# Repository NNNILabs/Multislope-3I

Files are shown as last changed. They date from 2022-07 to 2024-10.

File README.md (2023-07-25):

# Multislope 3I 
## Introduction
This repository contains hardware and software files for the third multislope prototype board, designated 3I. This is the most complete and proper version of the PCB so far, including a proper 8-resistor network, an LM399/ADR1399 reference, composite integrator (with two SOIC-8 footprints), shielding on the integrator summing node and test points to easily probe crucial nodes. 
History and operation are documented extensively [here](https://hackaday.io/project/190528-multislope-adc).
## Project Motivation
The second prototype PCB was completed hastily with not much thought put into either layout or choice of parts, so a better-designed (and hopefully better-evaluated) board was in order. 
## Usage
The KiCAD project files can be used to generate gerber files, which can be used to manufacture the PCBs. The code is written in C/C++ in the VScode development environment. Detailed instructions on how to compile the software will be added later. A .uf2 file is present in the project outputs which can be uploaded directly to the Pi Pico. 
## List of Files
- Hardware: KiCAD PCB design files, BOM and schematic. 
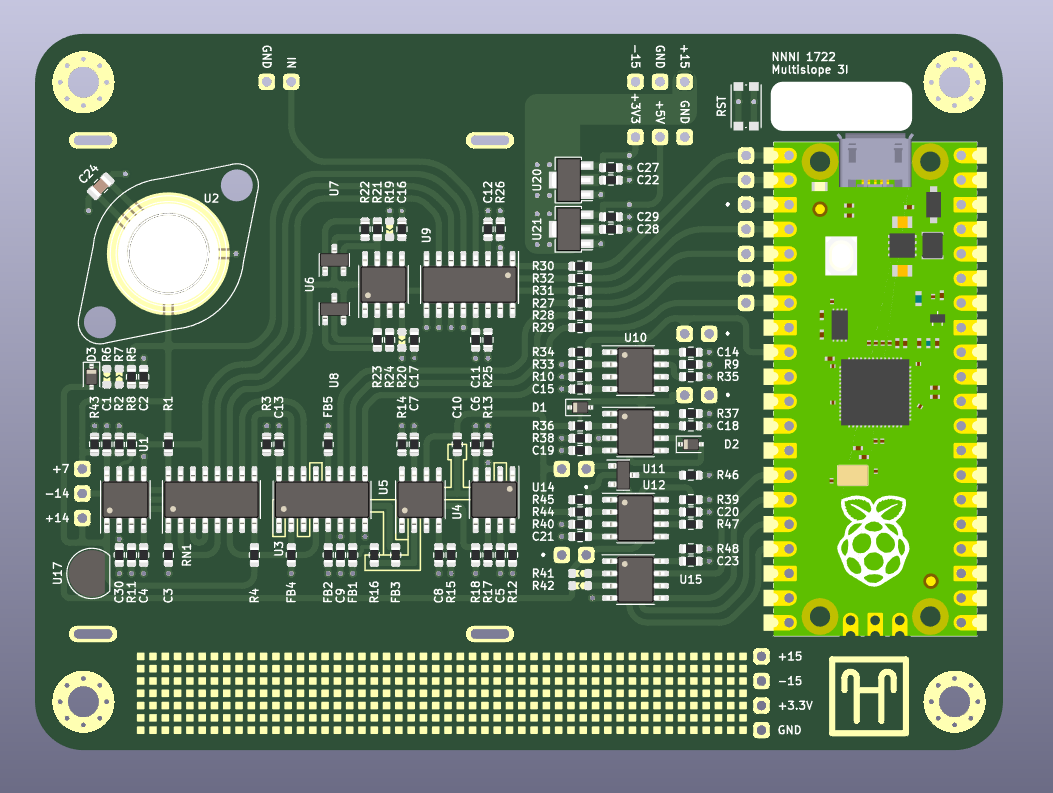
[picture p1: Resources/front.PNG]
Front side of the PCB

- Software: C/C++ code, uf2 file for direct upload. 
- Resources: Infographics
## Application Examples
- The readings from the overall converter (PWM counts and residue) were noisy, and the raw readings from the MCP3202 residue ADC were noisy and contained unexplained banding. Linearity shows a parabolic curve, probably because of wrong constants or small mismatches in switch resistances. 
### Linearity
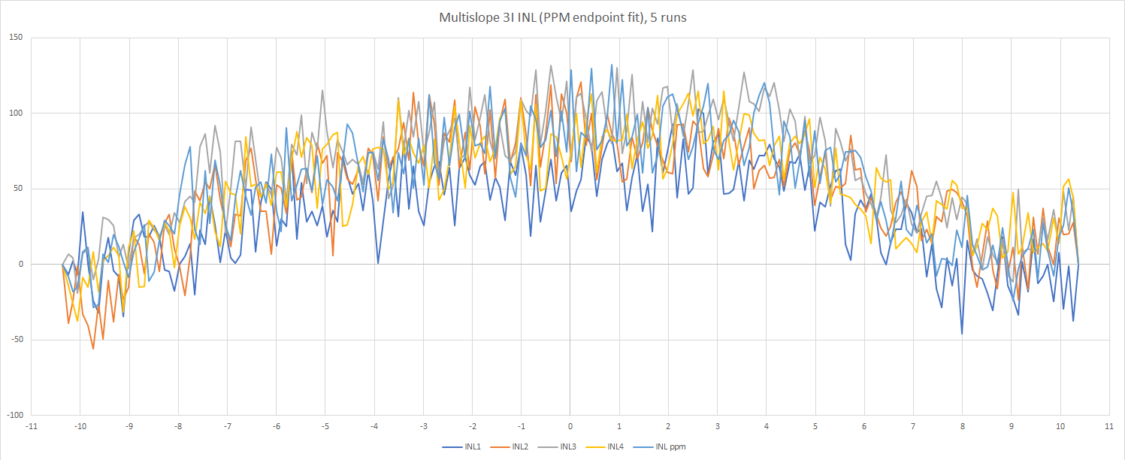
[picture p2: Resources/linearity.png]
Linearity

### MCP3202 Raw Data (Detail)
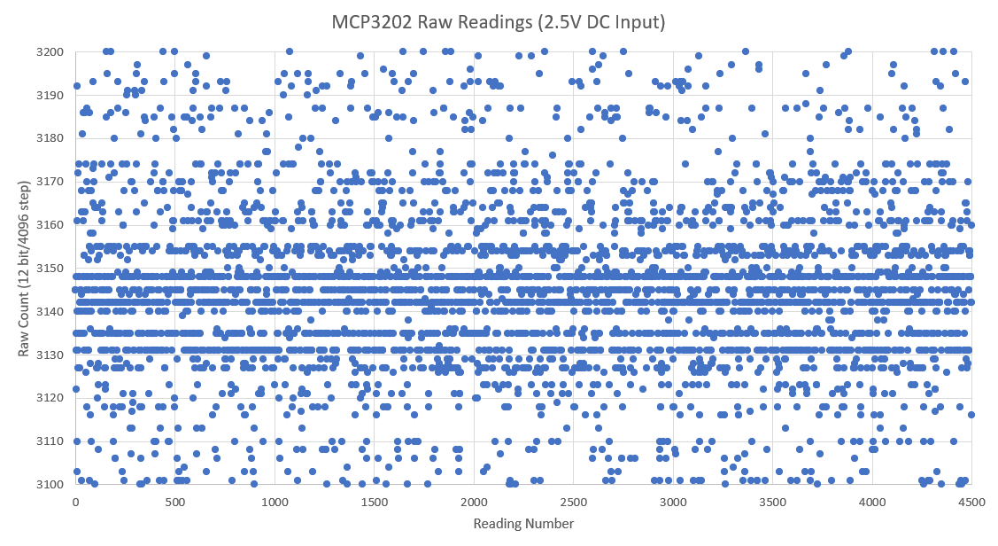
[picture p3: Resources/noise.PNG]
Noise

### Cause
- Reading noise was [determined](https://hackaday.io/project/190528-multislope-adc/log/218489-a-path-forward) to be caused by poor layout and decoupling around the MCP3202 residue ADC. 
- Linearity bell curve could be caused by input resistor's PCR.
## Notes
- An interactive Excel document is provided in the Resources folder, with a slider to vary the residue constant to visually determine the best constant to reconcile runup and residue readings. Update: Excel file broke somehow, but you can still see the effect of moving the slider in the video linked below, timestamp [10:15](https://youtu.be/aNtOfKR7sto?t=615).
- Another version of the converter is in development, with improvements to speed, resolution and noise. 
## Links
https://www.youtube.com/watch?v=aNtOfKR7sto

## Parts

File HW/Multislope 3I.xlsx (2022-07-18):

Comment | Designator | Footprint | LCSC Part #
1uf Unpolarized capacitor, small symbol | C1,C4,C5,C6,C7,C8,C11,C12,C13,C14,C15,C16,C17,C18,C19,C20,C21,C22,C23,C25,C26,C27,C28,C29,C30 | R_0603_1608Metric | C15849
1uF Unpolarized capacitor, small symbol | C2 | R_0603_1608Metric | C15849
100nF Unpolarized capacitor, small symbol | C3 | R_0603_1608Metric | C14663
100pF Unpolarized capacitor, small symbol | C9 | R_0603_1608Metric | C342908
1nF Unpolarized capacitor, small symbol | C10 | R_0603_1608Metric | C342910
1uF Unpolarized capacitor, small symbol | C24 | C_0805_2012Metric | C28323
4148 Diode | D1,D2 | D_SOD-323 | C2128
FB Ferrite bead, small symbol | FB1,FB2,FB3,FB4,FB5 | R_0603_1608Metric | C1002
MountingHole Mounting Hole without connection | H1,H2,H3,H4 | MountingHole_3.2mm_M3_Pad_Via
INT Generic connector, single row, 01x02, script generated (kicad-library-utils/schlib/autogen/connector/) | J1 | PinHeader_1x02_P2.54mm_Vertical
TEST Generic connector, single row, 01x07, script generated (kicad-library-utils/schlib/autogen/connector/) | J2 | PinHeader_1x07_P2.54mm_Vertical
COMP Generic connector, single row, 01x02, script generated (kicad-library-utils/schlib/autogen/connector/) | J3 | PinHeader_1x02_P2.54mm_Vertical
SLOT Generic connector, single row, 01x01, script generated (kicad-library-utils/schlib/autogen/connector/) | J4,J5,J6,J9 | PinHeader_1x01_P2.54mm_Vertical
SLOPE2 Generic connector, single row, 01x02, script generated (kicad-library-utils/schlib/autogen/connector/) | J7 | PinHeader_1x02_P2.54mm_Vertical
PWR Generic connector, single row, 01x03, script generated (kicad-library-utils/schlib/autogen/connector/) | J8,J15 | PinHeader_1x03_P2.54mm_Vertical
PWR Generic connector, single row, 01x04, script generated (kicad-library-utils/schlib/autogen/connector/) | J10 | PinHeader_1x04_P2.54mm_Vertical
TEST Generic connector, single row, 01x03, script generated (kicad-library-utils/schlib/autogen/connector/) | J11 | PinHeader_1x03_P2.54mm_Vertical
UART Generic connector, single row, 01x04, script generated (kicad-library-utils/schlib/autogen/connector/) | J12 | PinHeader_1x04_P2.54mm_Vertical
INPUT Generic connector, single row, 01x02, script generated (kicad-library-utils/schlib/autogen/connector/) | J13 | PinHeader_1x02_P2.54mm_Vertical
SLOPE Generic connector, single row, 01x02, script generated (kicad-library-utils/schlib/autogen/connector/) | J14 | PinHeader_1x02_P2.54mm_Vertical
REF CASE Housing | N1 | Ref Case
0R Resistor | R1,R4,R8 | R_0603_1608Metric
10R Resistor | R2,R3,R9,R10,R11,R12,R13,R14,R15,R25,R26,R37,R38,R39,R40,R48,R49 | R_0603_1608Metric | C22859
5R1 Resistor | R5 | R_0603_1608Metric | C25197
0R Resistor | R6,R7,R19,R20,R41,R42 | 0603 Jumper
100R Resistor | R16 | R_0603_1608Metric | C22775
10K Resistor | R17,R21,R22,R23,R24,R36 | R_0603_1608Metric | C25804
1K Resistor | R18,R27,R28,R29,R30,R31,R32,R33,R35 | R_0603_1608Metric | C21190
100K Resistor | R34 | R_0603_1608Metric | C25803
51K Resistor | R44 | R_0603_1608Metric | C23196
24K Resistor | R45 | R_0603_1608Metric | C23352
5K6 Resistor | R46 | R_0603_1608Metric | C23189
15K Resistor | R47 | R_0603_1608Metric | C22809
10K 8 resistor network, parallel topology, split | RN1 | SOIC-16_3.9x9.9mm_P1.27mm
RST Single Pole Single Throw (SPST) switch | SW1 | SW_Push_1P1T_NO_CK_KMR2
OPA21xx Dual 36V, Precision, Rail-to-Rail Input/Output, Low Offset Voltage, Operational Amplifier, SOIC-8 | U1 | SOIC-8_3.9x4.9mm_P1.27mm
LM399 Precision Reference, 6.95V, Buried Zener Diode with Thermal Shielding Can, TO-46-4 | U2 | Analog_TO-46-4_ThermalShield
CD4053B CMOS triple 2-channel analog multiplexer/demultiplexer, TSSOP-16/DIP-16/SOIC-16 | U3 | SOIC-16_3.9x9.9mm_P1.27mm
OPA1xx | U4,U5,U6 | SOIC-8_3.9x4.9mm_P1.27mm
431 Shunt Regulator, SOT-23 | U7,U8,U14 | SOT-23 | C3113
408 8-channel iCMOS analog multiplexer, 4.7 Ohm Ron, 60 MHz, TSSOP-16 | U9 | SOIC-16_3.9x9.9mm_P1.27mm
LM311 | U10 | SOIC-8_3.9x4.9mm_P1.27mm
NE5534 | U11 | SOIC-8_3.9x4.9mm_P1.27mm | C9916
OPA197 | U12 | SOIC-8_3.9x4.9mm_P1.27mm
MCP3202 A/D Converter, 12-Bit, 2-Channel, SPI Interface, 2.7V-5.5V | U15 | SOIC-8_3.9x4.9mm_P1.27mm | C56997
Pico | U16 | RPi_Pico_SMD_TH
LM35 Precision centigrade temperature sensor, TO-92 | U17 | TO-92
ADuM121N Dual-channel digital isolator,1.8 to 5V, 150Mbs, 3kV | U18 | SOIC-8_3.9x4.9mm_P1.27mm | C190783
HT7533 100mA Low Dropout Voltage Regulator, Fixed Output, SOT89 | U20 | SOT-89-3 | C14289
HT7550 100mA Low Dropout Voltage Regulator, Fixed Output, SOT89 | U21 | SOT-89-3 | C16106

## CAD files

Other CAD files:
HW/gerber/Multislope 3I-User_1.dxf

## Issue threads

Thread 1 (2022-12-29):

hey there

overloadchez, 2022-12-29:
hi nnni. this is overlord cheese, a kid you used to talk to on discoird. I got sent to a wilderness therapy and am now at a tbs. im still into electronics and am currently reading a book on circuit analysis (well, more like pushing my way through it, its suuuper boring)
miss ya. everything else was blocked and i dont have much time so yeah this was the on;ly place i could contact you

NNNIIndia, 2022-12-29:
Hi, glad to know you're doing okay! I've been wondering for a long time as well.
I don't really like to read books about circuits because it's all so much maths. The Art of Electronics is the only thing I would consider a good read, and there's a PDF version available online.
I hope everything works out fine and you will be active on Discord again.

overloadchez2, 2022-12-30:
I'll take what I can get with circuits right now, plus I don't mind math (all I lack in terms of know how is calculus, and I'll be learning that soon).
As for AOE, I've already asked my parents for it, and a PDF wouldn't work, cause, well... I don't really get to use screens. On that note, someday I will be on discord again but not anytime soon. Well, at least not consistently. it may be over a year before I can do that with the restrictions here.

...But I look forward to talking to you then
:)

NNNIIndia, 2022-12-30:
No problem, see you then!
P.S. AoE 3 is like 50USD, you can probably get the second edition cheaper but wouldn't recommend it.

Closed 2023-06-16.

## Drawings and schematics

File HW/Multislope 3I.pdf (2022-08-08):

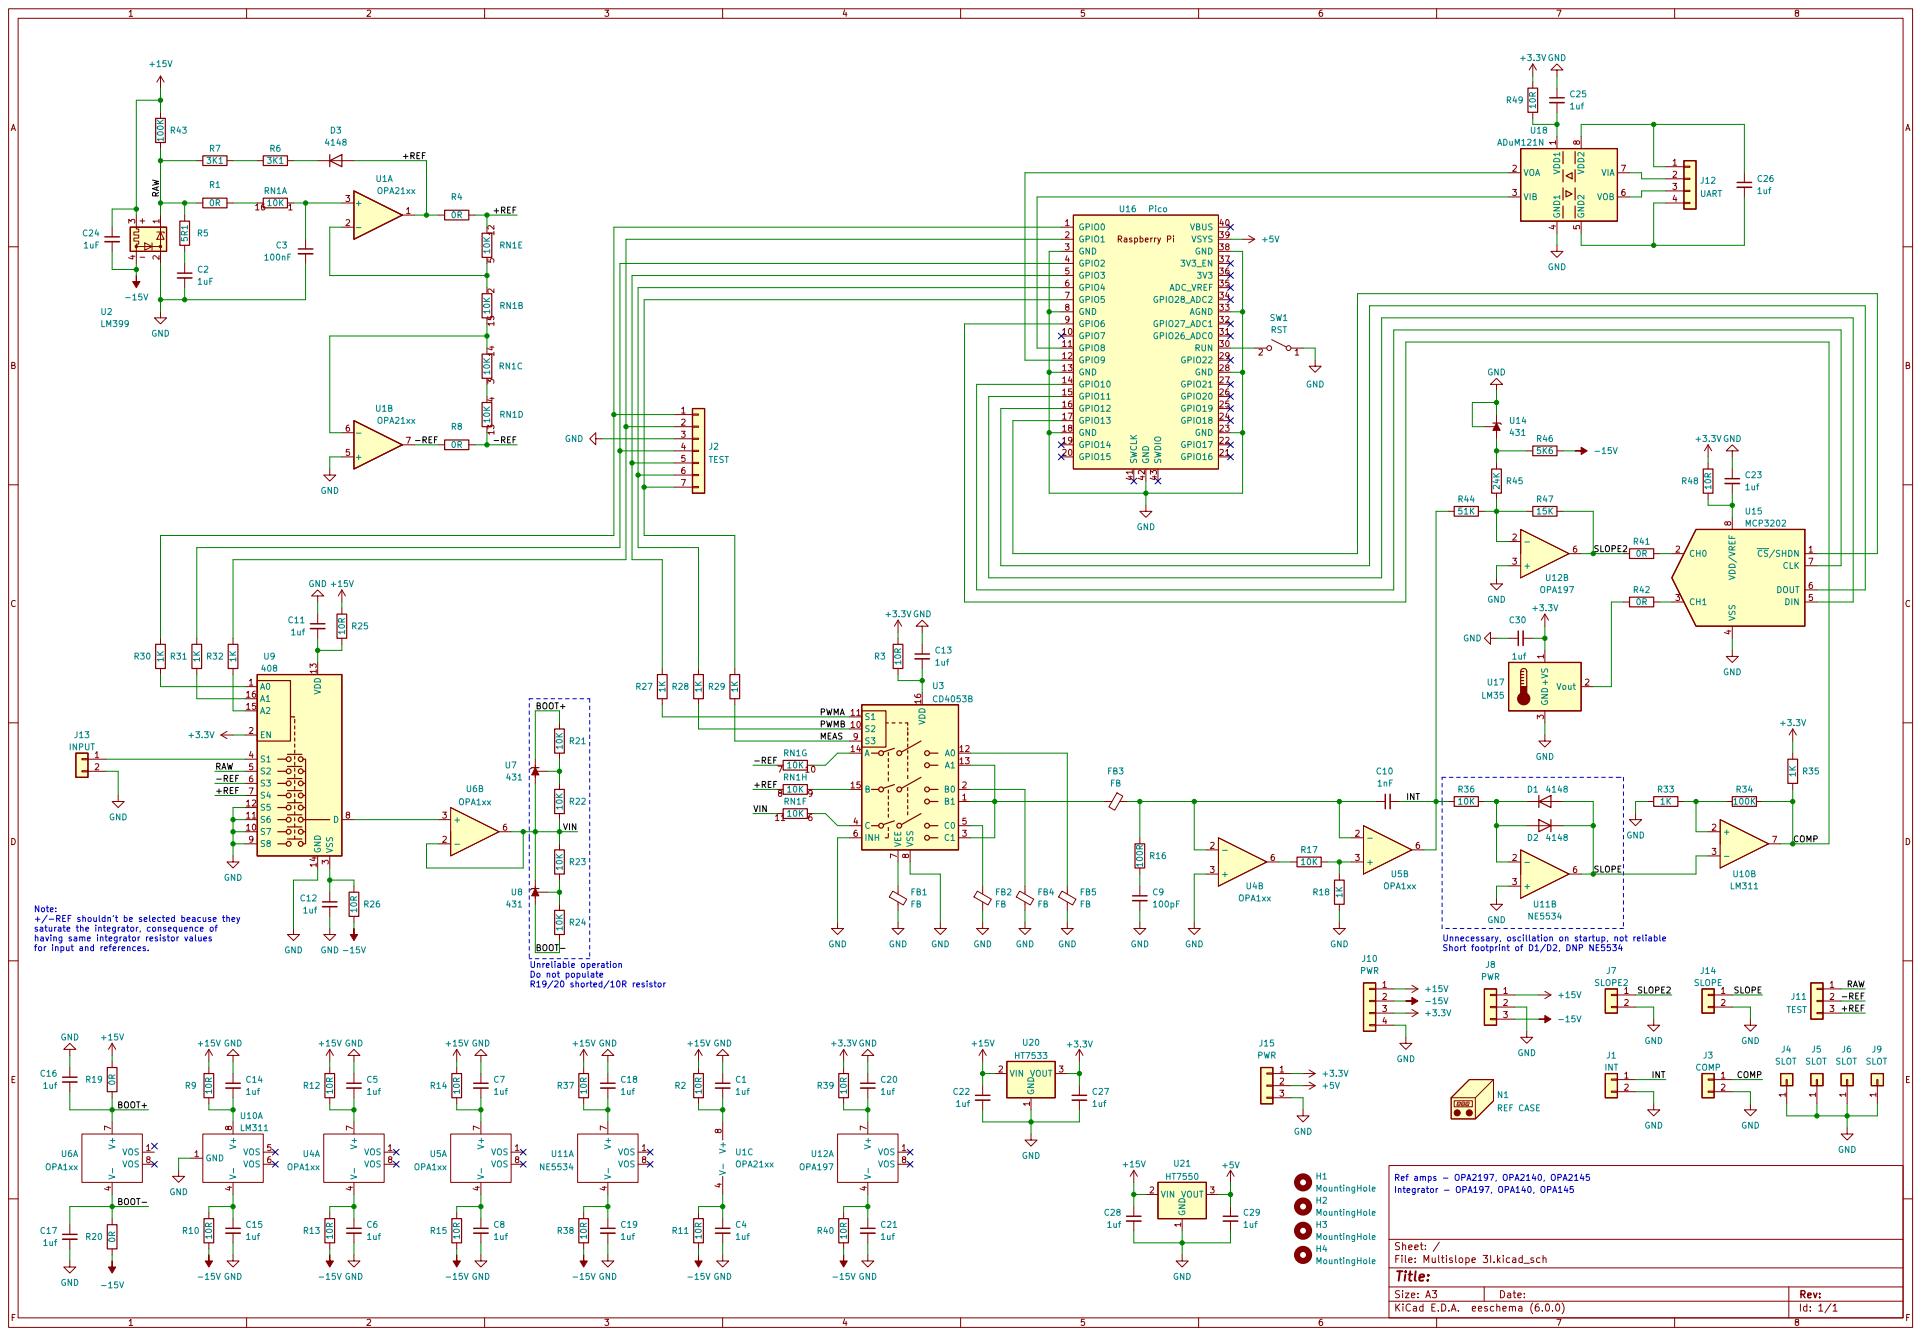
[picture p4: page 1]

saturate the integrator, consequence of
having same integrator resistor values
for input and references.

Short footprint of D1/D2, DNP NE5534

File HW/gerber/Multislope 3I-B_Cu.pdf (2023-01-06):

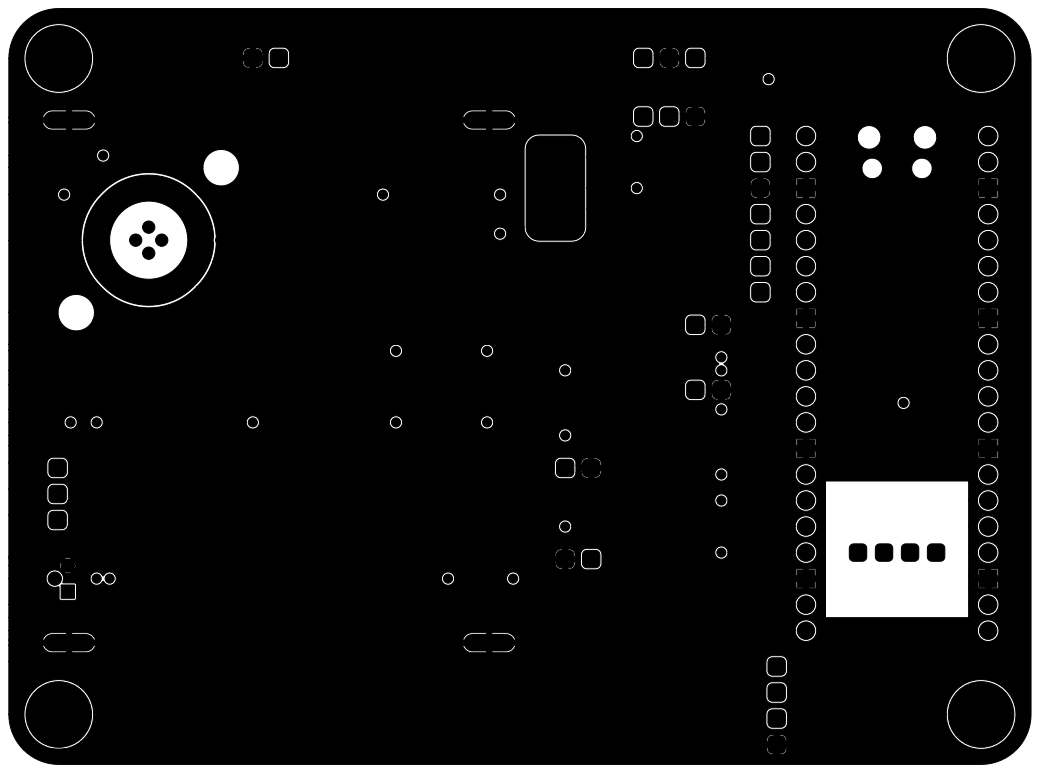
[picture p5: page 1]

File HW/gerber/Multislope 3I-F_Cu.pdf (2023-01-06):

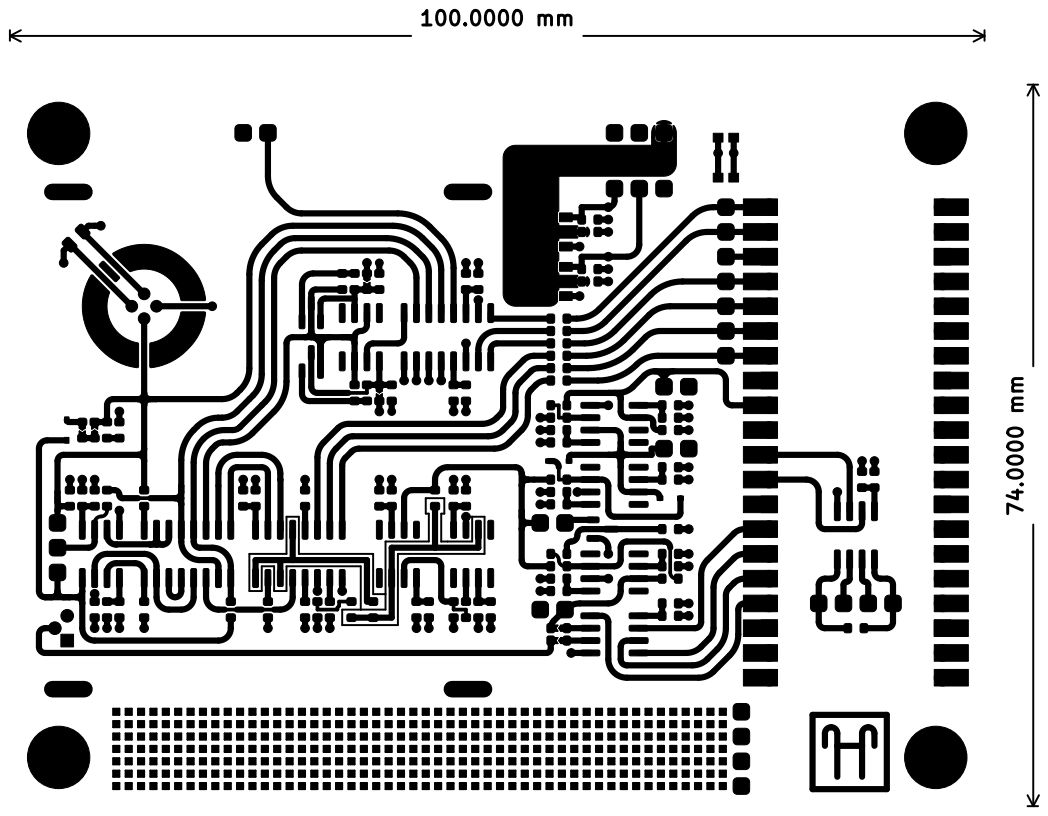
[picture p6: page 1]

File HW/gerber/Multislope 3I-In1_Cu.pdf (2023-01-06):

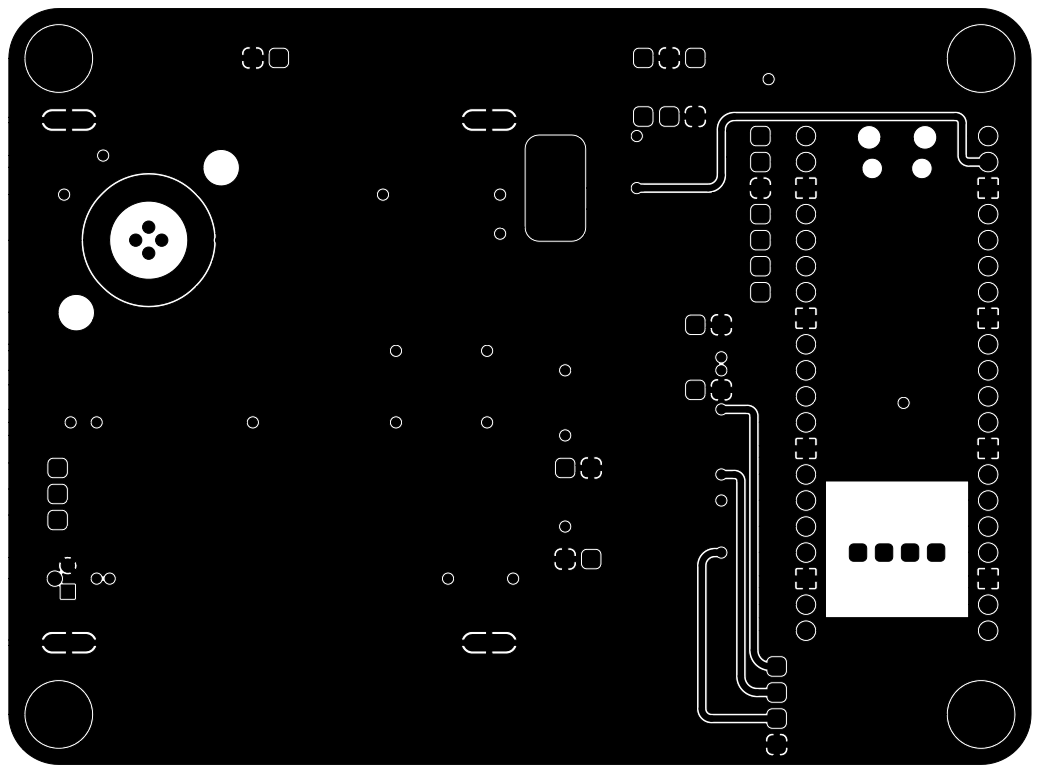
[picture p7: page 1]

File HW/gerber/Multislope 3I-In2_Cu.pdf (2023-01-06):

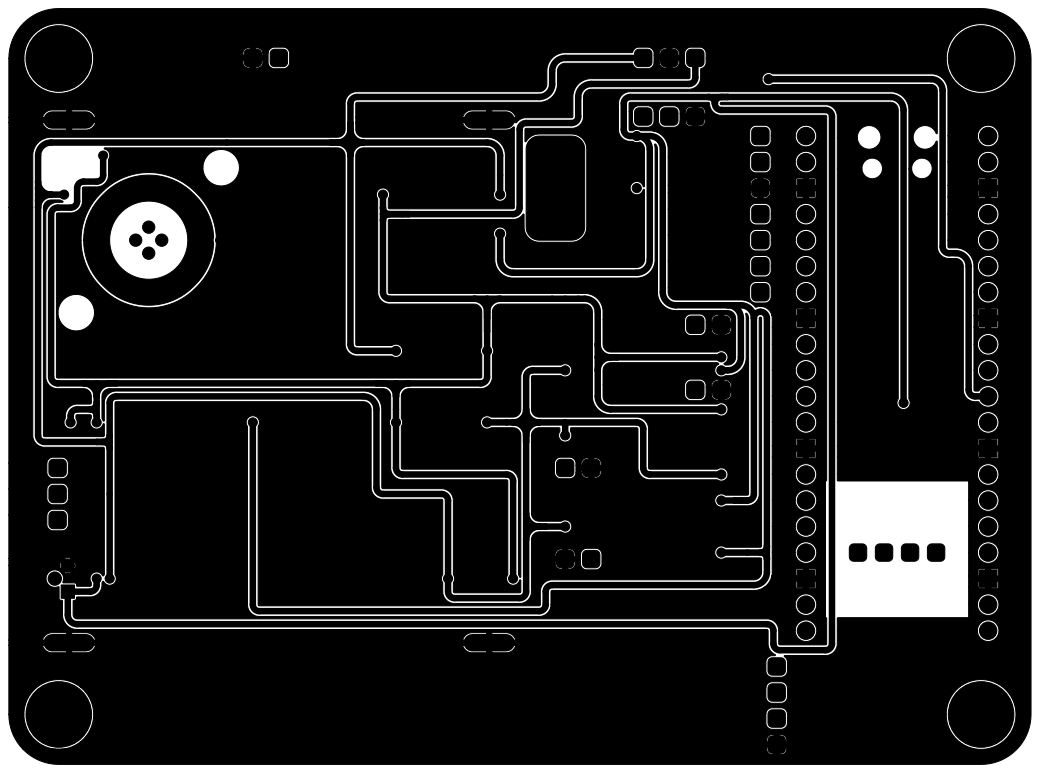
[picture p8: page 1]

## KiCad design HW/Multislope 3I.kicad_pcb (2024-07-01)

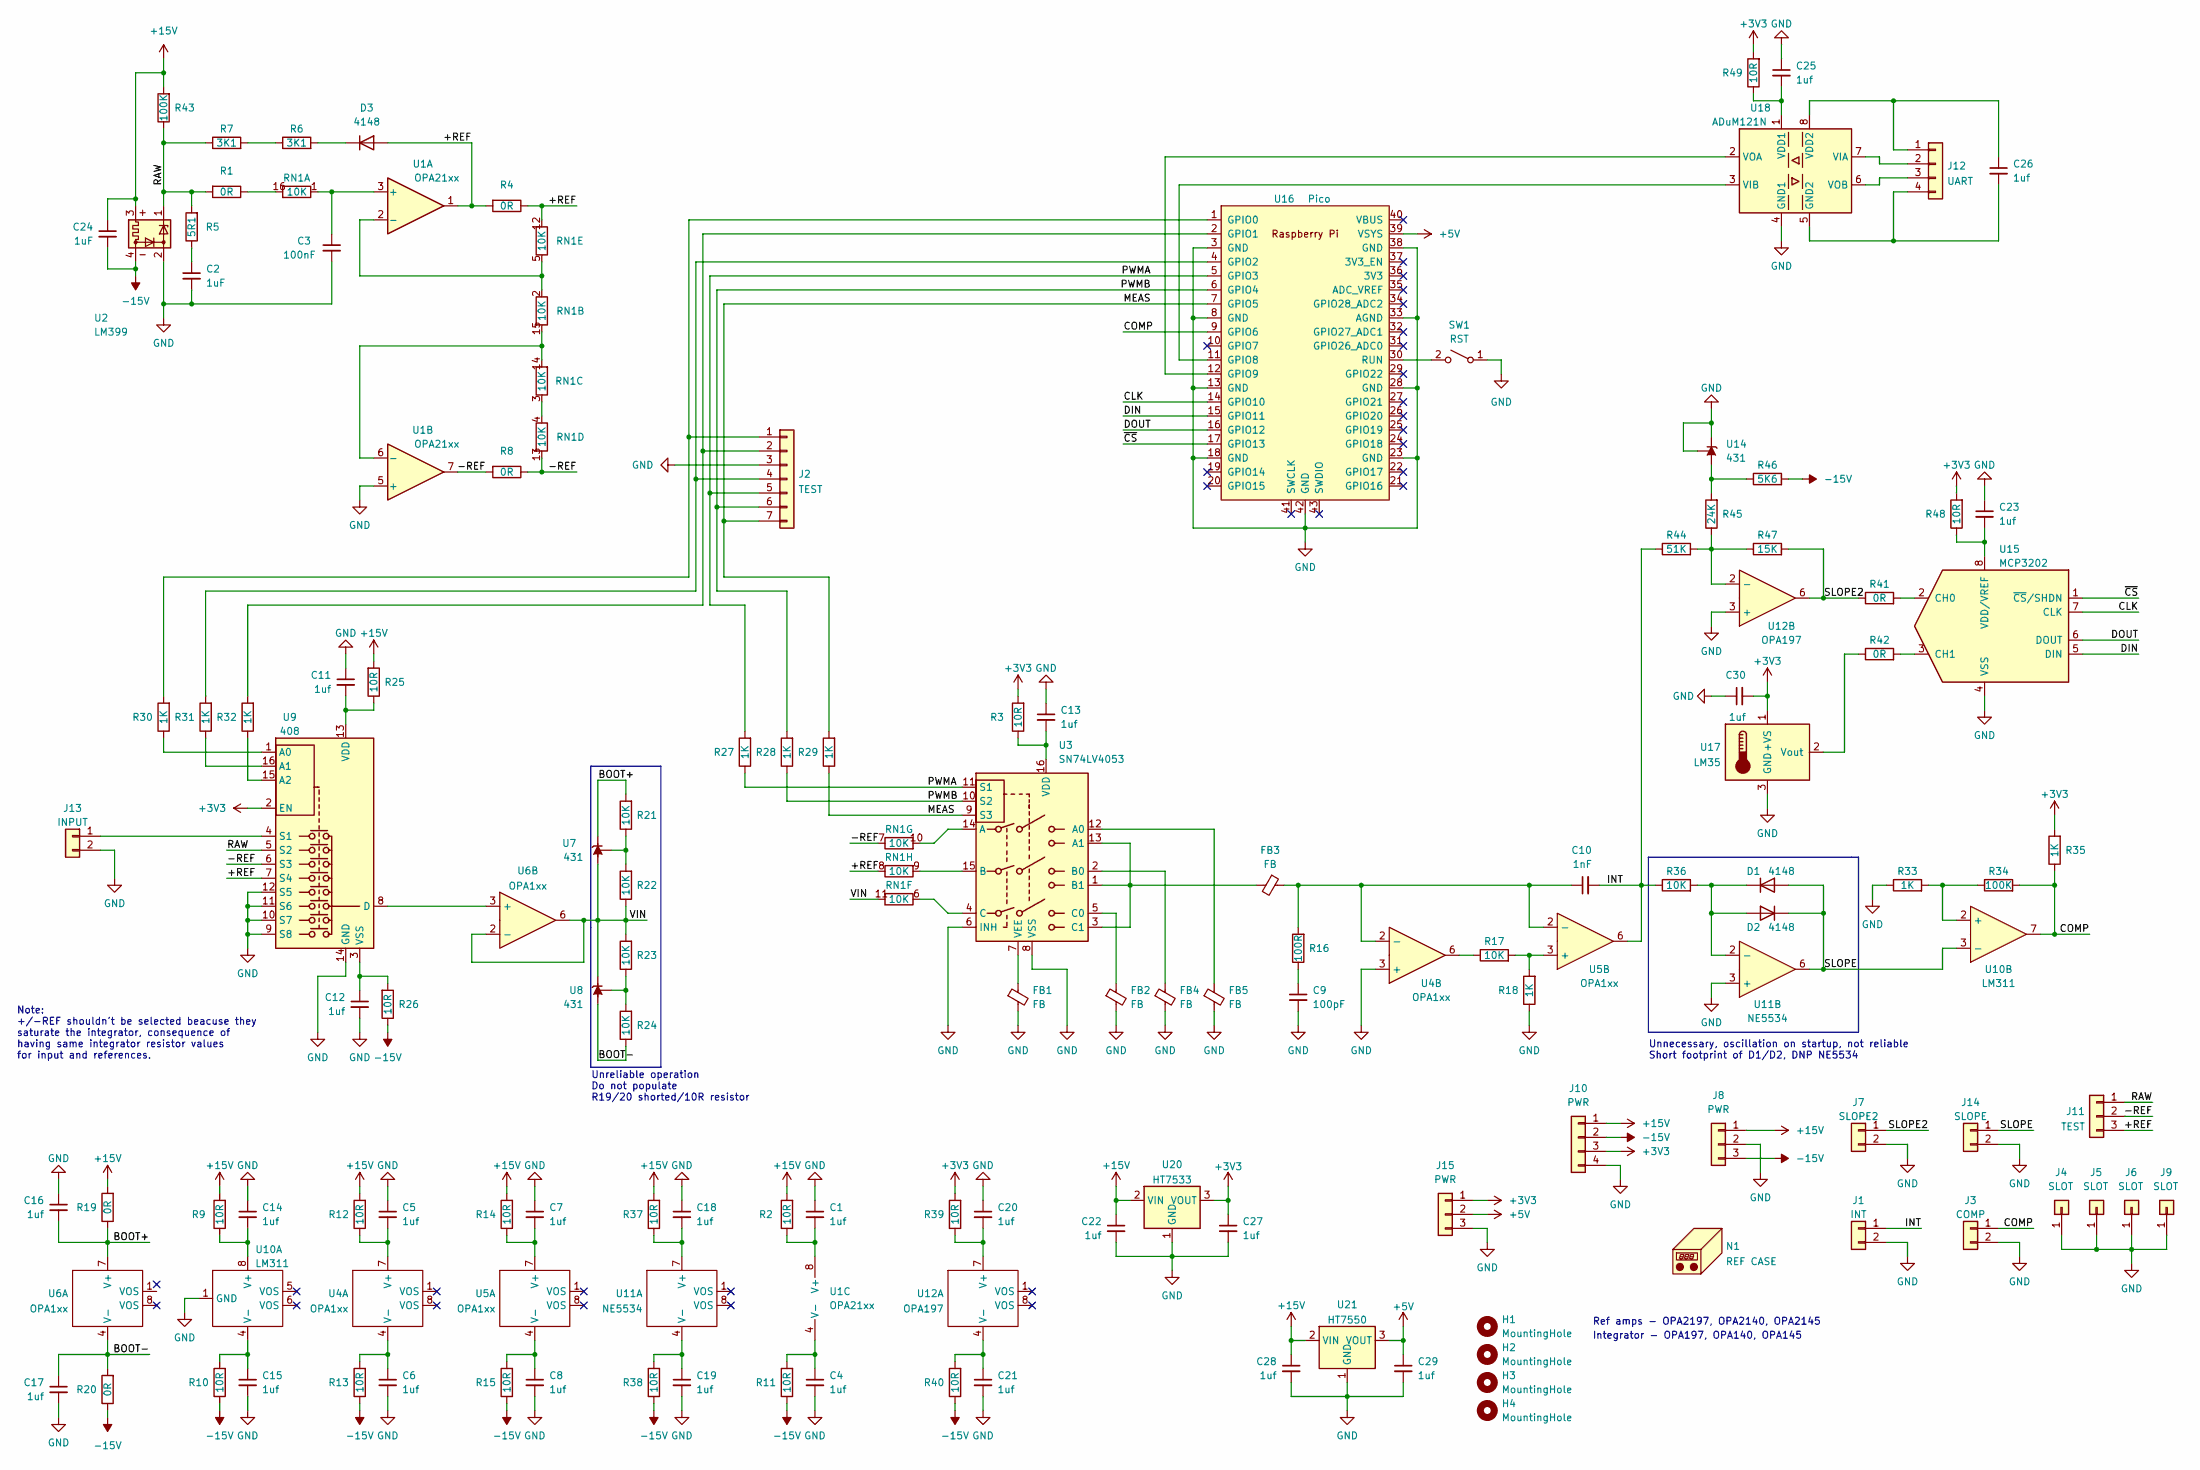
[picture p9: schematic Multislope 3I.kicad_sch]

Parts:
C1, C4, C5, C6, C7, C8, C11, C12, C13, C14, C15, C16, C17, C18, C19, C20, C21, C22, C23, C25, C26, C27, C28, C29, C30: 1uf; R_0603_1608Metric
C2: 1uF; R_0603_1608Metric
C3: 100nF; R_0603_1608Metric
C9: 100pF; R_0603_1608Metric
C10: 1nF; R_0603_1608Metric
C24: 1uF; C_0805_2012Metric
D1, D2, D3: 4148; D_SOD-323
FB1, FB2, FB3, FB4, FB5: FB; R_0603_1608Metric
H1, H2, H3, H4: MountingHole; MountingHole_3.2mm_M3_Pad_Via
J1: INT; PinHeader_1x02_P2.54mm_Vertical
J2: TEST; PinHeader_1x07_P2.54mm_Vertical
J3: COMP; PinHeader_1x02_P2.54mm_Vertical
J4, J5, J6, J9: SLOT; PinHeader_1x01_P2.54mm_Vertical
J7: SLOPE2; PinHeader_1x02_P2.54mm_Vertical
J8, J15: PWR; PinHeader_1x03_P2.54mm_Vertical
J10: PWR; PinHeader_1x04_P2.54mm_Vertical
J11: TEST; PinHeader_1x03_P2.54mm_Vertical
J12: UART; PinHeader_1x04_P2.54mm_Vertical
J13: INPUT; PinHeader_1x02_P2.54mm_Vertical
J14: SLOPE; PinHeader_1x02_P2.54mm_Vertical
N1: REF CASE; Ref Case
R1, R4, R8: 0R; R_0603_1608Metric
R2, R3, R9, R10, R11, R12, R13, R14, R15, R25, R26, R37, R38, R39, R40, R48, R49: 10R; R_0603_1608Metric
R5: 5R1; R_0603_1608Metric
R6, R7: 3K1; 0603 Jumper
R16: 100R; R_0603_1608Metric
R17, R21, R22, R23, R24, R36: 10K; R_0603_1608Metric
R18, R27, R28, R29, R30, R31, R32, R33, R35: 1K; R_0603_1608Metric
R19, R20, R41, R42: 0R; 0603 Jumper
R34, R43: 100K; R_0603_1608Metric
R44: 51K; R_0603_1608Metric
R45: 24K; R_0603_1608Metric
R46: 5K6; R_0603_1608Metric
R47: 15K; R_0603_1608Metric
RN1: 10K; SOIC-16_3.9x9.9mm_P1.27mm
SW1: RST; SW_Push_1P1T_NO_CK_KMR2
U1: OPA21xx; SOIC-8_3.9x4.9mm_P1.27mm
U2: LM399; Analog_TO-46-4_ThermalShield
U3: SN74LV4053; SOIC-16_3.9x9.9mm_P1.27mm
U4, U5, U6: OPA1xx; SOIC-8_3.9x4.9mm_P1.27mm
U7, U8, U14: 431; SOT-23
U9: 408; SOIC-16_3.9x9.9mm_P1.27mm
U10: LM311; SOIC-8_3.9x4.9mm_P1.27mm
U11: NE5534; SOIC-8_3.9x4.9mm_P1.27mm
U12: OPA197; SOIC-8_3.9x4.9mm_P1.27mm
U15: MCP3202; SOIC-8_3.9x4.9mm_P1.27mm
U16: Pico; RPi_Pico_SMD_TH
U17: LM35; TO-92
U18: ADuM121N; SOIC-8_3.9x4.9mm_P1.27mm
U20: HT7533; SOT-89-3
U21: HT7550; SOT-89-3

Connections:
+3V3: C27.1, C30.2, J10.3, J15.1, R3.2, R35.2, R39.2, R48.2, R49.2, U9.2 (EN), U17.1 (+VS), U20.3 (VOUT)
+5V: C29.1, J15.2, U16.39 (VSYS), U21.3 (VOUT)
+15V: C22.1, C24.1, C28.1, J8.1, J10.1, R2.2, R9.2, R12.2, R14.2, R19.2, R25.2, R37.2, R43.2, U2.3, U20.2 (VIN), U21.2 (VIN)
-15V: C24.2, J8.3, J10.2, R10.1, R11.1, R13.1, R15.1, R20.1, R26.1, R38.1, R40.1, R46.2, U2.4
/+REF: D3.2 (A), J11.3, R4.1, R4.2, RN1.8 (R8.1), RN1.12 (R5.2), U1.1, U9.7 (S4)
/-REF: J11.2, R8.1, R8.2, RN1.7 (R7.1), RN1.13 (R4.2), U1.7, U9.6 (S3)
/BOOT+: C16.2, R19.1, R21.2, U6.7 (V+), U7.2 (K)
/BOOT-: C17.1, R20.2, R24.1, U6.4 (V-), U8.3 (A)
/COMP: J3.1, R34.2, R35.1, U10.7, U16.9 (GPIO6)
/INT: C10.2, J1.1, R36.1, R44.1, U5.6
/MEAS: J2.7, R29.1, R29.2, U3.9 (S3), U16.7 (GPIO5)
/PWMA: J2.5, R27.1, R27.2, U3.11 (S1), U16.5 (GPIO3)
/PWMB: J2.6, R28.1, R28.2, U3.10 (S2), U16.6 (GPIO4)
/RAW: J11.1, R1.2, R5.2, R7.1, R43.1, U2.1, U9.5 (S2)
/SLOPE: D1.2 (A), D2.1 (K), J14.1, U10.3 (-), U11.6
/SLOPE2: J7.1, R41.1, R47.2, U12.6
/VIN: R22.1, R23.2, RN1.11 (R6.2), U6.2 (-), U6.6, U7.3 (A), U8.2 (K)
GND: C1.1, C2.2, C3.2, C4.2, C5.1, C6.2, C7.1, C8.2, C9.2, C11.1, C12.2, C13.1, C14.1, C15.2, C16.1, C17.2, C18.1, C19.2, C20.1, C21.2, C22.2, C23.1, C25.1, C27.2, C28.2, C29.2, C30.1, FB1.2, FB2.2, FB4.2, FB5.2, J1.2, J2.3, J3.2, J4.1, J5.1, J6.1, J7.2, J8.2, J9.1, J10.4, J13.2, J14.2, J15.3, R18.1, R33.1, SW1.1 (A), U1.5 (+), U2.2, U3.6 (INH), U3.8 (VSS), U4.3 (+), U9.9 (S8), U9.10 (S7), U9.11 (S6), U9.12 (S5), U9.14 (GND), U10.1 (GND), U11.3 (+), U12.3 (+), U14.1 (REF), U14.2 (K), U15.4 (VSS), U16.3 (GND), U16.8 (GND), U16.13 (GND), U16.18 (GND), U16.23 (GND), U16.28 (GND), U16.33 (AGND), U16.38 (GND), U16.42 (GND), U17.3 (GND), U18.4 (GND1), U20.1 (GND), U21.1 (GND)
unnamed: C2.1, R5.1
unnamed: C9.1, R16.1
unnamed: D1.1 (K), D2.2 (A), R36.2, U11.2 (-)
unnamed: D3.1 (K), R6.2
unnamed: J2.1, R30.2, U16.1 (GPIO0)
unnamed: J2.2, R32.2, U16.2 (GPIO1)
unnamed: J2.4, R31.2, U16.4 (GPIO2)
unnamed: C26.1, J12.1, U18.8 (VDD2)
unnamed: J12.2, U18.7 (VIA)
unnamed: J12.3, U18.6 (VOB)
unnamed: C26.2, J12.4, U18.5 (GND2)
unnamed: J13.1, U9.4 (S1)
unnamed: R6.1, R7.2
unnamed: R17.1, U4.6
unnamed: C3.1, RN1.1 (R1.1), U1.3 (+)
unnamed: R1.1, RN1.16 (R1.2)
unnamed: RN1.2 (R2.1), RN1.5 (R5.1), U1.2 (-)
unnamed: RN1.14 (R3.2), RN1.15 (R2.2), U1.6 (-)
unnamed: RN1.3 (R3.1), RN1.4 (R4.1)
unnamed: RN1.6 (R6.1), U3.4 (C)
unnamed: RN1.10 (R7.2), U3.14 (A)
unnamed: RN1.9 (R8.2), U3.15 (B)
unnamed: SW1.2 (B), U16.30 (RUN)
unnamed: C1.2, R2.1, U1.8 (V+)
unnamed: C4.1, R11.2, U1.4 (V-)
unnamed: FB5.1, U3.12 (A0)
unnamed: FB3.2, U3.1 (B1), U3.3 (C1), U3.13 (A1)
unnamed: FB4.1, U3.2 (B0)
unnamed: FB2.1, U3.5 (C0)
unnamed: C13.2, R3.1, U3.16 (VDD)
unnamed: FB1.1, U3.7 (VEE)
unnamed: C5.2, R12.1, U4.7 (V+)
unnamed: C6.1, R13.2, U4.4 (V-)
unnamed: C10.1, FB3.1, R16.2, U4.2 (-), U5.2 (-)
unnamed: C7.2, R14.1, U5.7 (V+)
unnamed: C8.1, R15.2, U5.4 (V-)
unnamed: R17.2, R18.2, U5.3 (+)
unnamed: U6.3 (+), U9.8 (D)
unnamed: R21.1, R22.2, U7.1 (REF)
unnamed: R23.1, R24.2, U8.1 (REF)
unnamed: R30.1, U9.1 (A0)
unnamed: R31.1, U9.16 (A1)
unnamed: R32.1, U9.15 (A2)
unnamed: C11.2, R25.1, U9.13 (VDD)
unnamed: C12.1, R26.2, U9.3 (VSS)
unnamed: C14.2, R9.1, U10.8 (V+)
unnamed: C15.1, R10.2, U10.4 (V-)
unnamed: R33.2, R34.1, U10.2 (+)
unnamed: C18.2, R37.1, U11.7 (V+)
unnamed: C19.1, R38.2, U11.4 (V-)
unnamed: C20.2, R39.1, U12.7 (V+)
unnamed: C21.1, R40.2, U12.4 (V-)
unnamed: R44.2, R45.1, R47.1, U12.2 (-)
unnamed: R45.2, R46.1, U14.3 (A)
unnamed: R41.2, U15.2 (CH0)
unnamed: R42.2, U15.3 (CH1)
unnamed: U15.7 (CLK), U16.14 (GPIO10)
unnamed: U15.5 (DIN), U16.15 (GPIO11)
unnamed: U15.6 (DOUT), U16.16 (GPIO12)
unnamed: C23.2, R48.1, U15.8 (VDD/VREF)
unnamed: U15.1 (~CS/SHDN), U16.17 (GPIO13)
unnamed: U16.11 (GPIO8), U18.3 (VIB)
unnamed: U16.12 (GPIO9), U18.2 (VOA)
unnamed: R42.1, U17.2 (Vout)
unnamed: C25.2, R49.1, U18.1 (VDD1)

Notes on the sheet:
Ref amps - OPA2197, OPA2140, OPA2145
Unreliable operation Do not populate R19/20 shorted/10R resistor
Integrator - OPA197, OPA140, OPA145
Unnecessary, oscillation on startup, not reliable Short footprint of D1/D2, DNP NE5534
Note: +/-REF shouldn't be selected beacuse they saturate the integrator, consequence of having same integrator resistor values for input and references.

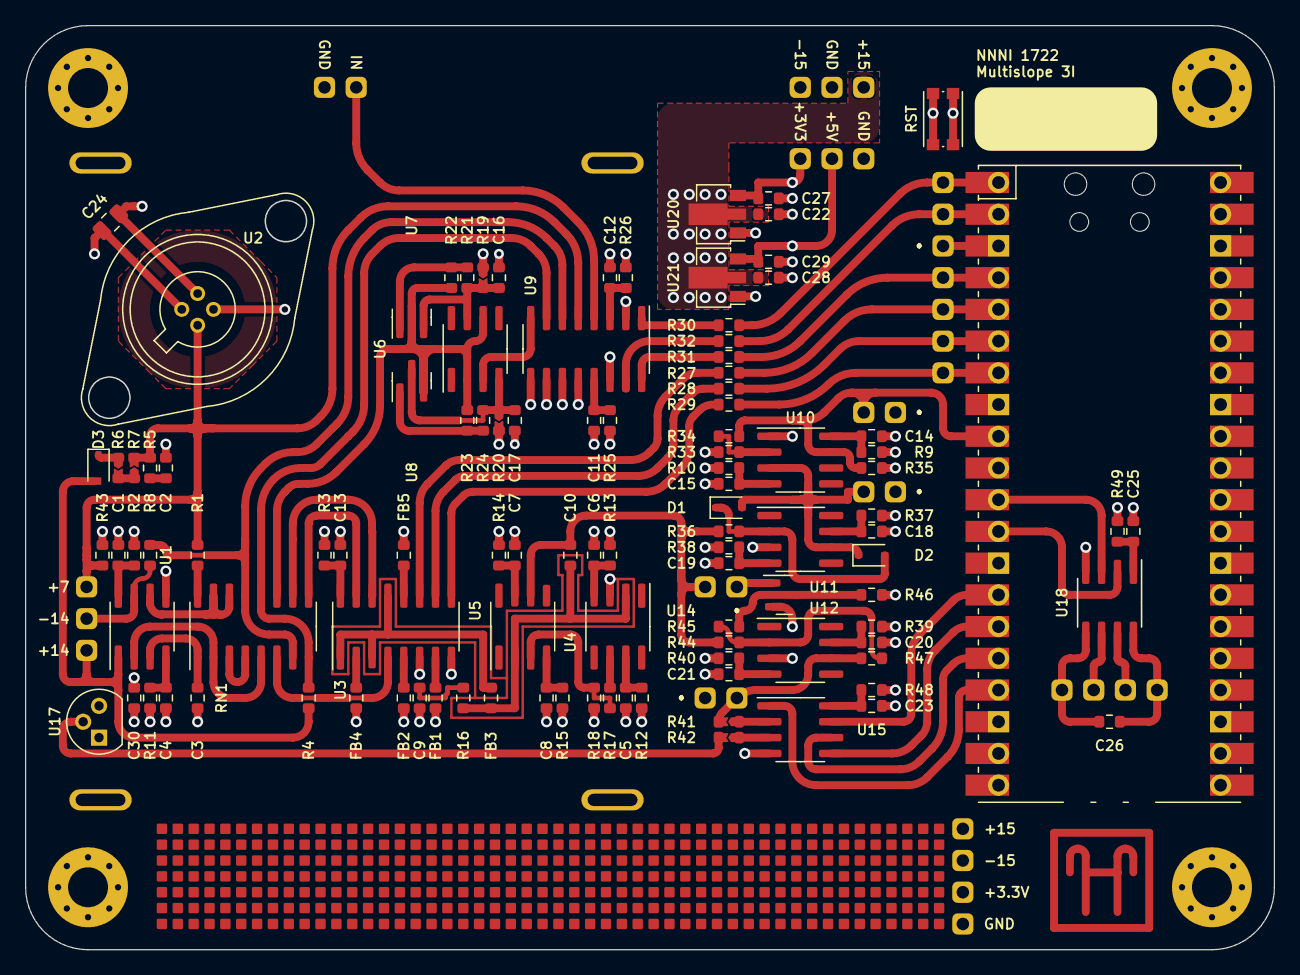
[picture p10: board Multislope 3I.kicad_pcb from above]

Board: 4 copper layers, 100.0 x 74.0 mm, 128 parts (0 on the bottom side), 83 nets.

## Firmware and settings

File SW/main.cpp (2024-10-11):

#include <stdio.h>
#include "pico/stdlib.h"
#include "hardware/gpio.h"
#include "hardware/pio.h"
#include "hardware/irq.h"

#include "ms.pio.h"
#include "lib/i2c_slave.h"

const float div = 40;
uint32_t pwmCycles = 1500;

const uint8_t MUX_A0 = 0;
const uint8_t MUX_A1 = 2;
const uint8_t MUX_A2 = 1;

const uint8_t PWMA = 3;                // need to be next to each other
const uint8_t PWMB = 4;                // need to be next to each other
const uint8_t MEAS = 5;
const uint8_t COMP = 6;

// Pinout notes for TMT multislope
// TMUX1134:
// S1: RESET (somehow)
// S2: -VREF
// S3: +VREF
// S4: VIN

const double vrefAbs = 6.85793; // Measured using K2000

double voltage = 0.0;

PIO pio;

uint multislopeSM;
uint residueSM;
uint calibrationSM;
uint rundownSM;

int32_t counts = 0;
int32_t residueBefore = 0;
int32_t residueAfter = 0;
int32_t RUU = 1540;
int32_t RUD = 1540;
int32_t rundownUp = 0;
int32_t rundownDown = 0;

int32_t gndCounts = 0;
int32_t rawCounts = 0;
int32_t inCounts = 0;
int32_t previousGndCounts = 0;
int32_t finalGroundCounts = 0;

int32_t runup_pos = 0;
int32_t runup_neg = 0;
int32_t rundown_pos = 0;
int32_t rundown_neg = 0;
int32_t residue_before = 0;
int32_t residue_after = 0;

int32_t N1, N2, N3;

int32_t result = 0;

uint32_t newInput = 0;
char inputBuffer[32] = {0};

// MCP3202 ADC
#define CS   13
#define CLK  12
#define MOSI 11
#define MISO 10

#define LED  25

enum muxState
{
    MUX_IN, 
    MUX_RAW,
    MUX_GND,
    MUX_POSREF,  // Implement if input resistor is > 10kΩ
    MUX_NEGREF   // Same as above
};

void setMuxState(enum muxState inputState)
{
    switch(inputState)
    {
        case MUX_IN:
            gpio_put(MUX_A0, false);
            gpio_put(MUX_A1, false);
            gpio_put(MUX_A2, false);
            break;

        case MUX_RAW:
            gpio_put(MUX_A0, true);
            gpio_put(MUX_A1, false);
            gpio_put(MUX_A2, false);
            break;
        
        case MUX_GND:
            gpio_put(MUX_A0, false);
            gpio_put(MUX_A1, false);
            gpio_put(MUX_A2, true);
            break;
    }
}

void get_counts(uint32_t countNum)
{
    gpio_put(LED, true);

    pio_sm_clear_fifos(pio, multislopeSM);
    pio_sm_clear_fifos(pio, residueSM);

    pio_sm_put_blocking(pio, multislopeSM, countNum - 1);         // write number of PWM cycles to runup state machine

    residueBefore = pio_sm_get_blocking(pio, residueSM);          // read pre-runup integrator state

    counts = ~pio_sm_get_blocking(pio, multislopeSM);             // read runup counts
    rundownUp = ~pio_sm_get_blocking(pio, multislopeSM);          // read rundown up counts
    rundownDown = ~pio_sm_get_blocking(pio, multislopeSM);        // read rundown down counts

    residueAfter = pio_sm_get_blocking(pio, residueSM);           // read post-runup integrator state

    runup_pos = pwmCycles - counts;
    runup_neg = counts;

    rundown_neg = rundownUp - counts;
    rundown_pos = rundownDown - rundownUp;

    residue_before = residueBefore & 0xFFF;
    residue_after = residueAfter & 0xFFF;

    gpio_put(LED, false);
}

void get_cal()
{
    sleep_ms(100);

    gpio_put(LED, true);

    uint32_t countOne = 0;
    uint32_t countTwo = 0;
    uint32_t countThree = 0;
    uint32_t countFour = 0;

    pio_sm_put_blocking(pio, calibrationSM, 1);

    countOne = pio_sm_get_blocking(pio, residueSM);
    countTwo = pio_sm_get_blocking(pio, residueSM);
    countThree = pio_sm_get_blocking(pio, residueSM);

    pio_sm_clear_fifos(pio, calibrationSM);
    pio_sm_clear_fifos(pio, residueSM);

    uint32_t R1 = (countTwo - countOne);
    uint32_t R2 = (countTwo - countThree);

    RUU = R2; // * 1.0001; // R2;
    RUD = R1; // * 0.9999; // R1;

    gpio_put(LED, false);

}

void get_result()
{
    N1 = N2 = N3 = 0;

    // N1 = (runup_neg * (15*RUU + 1*RUD)) - (runup_pos * (1*RUU + 15*RUD)); // Complementary PWM runup
    N1 = (runup_neg * (14*RUU)) - (runup_pos * (14*RUD)); // Jaromir runup
    N2 = (rundown_neg * RUU) - (rundown_pos * RUD);
    N3 = residue_after - residue_before;

    result = N1 + N2 + N3;

}

int main() 
{
    set_sys_clock_khz(96000, true);  
    stdio_init_all();

    i2c_init();

    gpio_init(LED);
    gpio_set_dir(LED, GPIO_OUT);

    gpio_init(MUX_A0);
    gpio_init(MUX_A1);
    gpio_init(MUX_A2);

    gpio_set_dir(MUX_A0, GPIO_OUT);
    gpio_set_dir(MUX_A1, GPIO_OUT);
    gpio_set_dir(MUX_A2, GPIO_OUT);
    
    sleep_us(10);

    gpio_init(13);
    gpio_set_dir(13, GPIO_OUT);
    gpio_put(13, false);

    pio = pio0;

    residueSM = 0; // pio_claim_unused_sm(pio, true);
    uint residueOffset = pio_add_program(pio, &residue_program);

    calibrationSM = 1; // pio_claim_unused_sm(pio, true);
    uint calibrationOffset = pio_add_program(pio, &calibration_program);

    residue_program_init(pio, residueSM, residueOffset, MISO, div);
    calibration_program_init(pio, calibrationSM, calibrationOffset, PWMA, COMP, div, MEAS);

    pio_sm_set_enabled(pio, calibrationSM, true);
    pio_sm_set_enabled(pio, residueSM, true);

    get_cal();

    sleep_ms(100);

    get_cal();

    // while(true)
    // {
    //     get_cal();
    //     sleep_ms(500);
    //     printf("%d, %d\n", RUU, RUD);
    // }

    pio_sm_set_enabled(pio, residueSM, false);
    pio_sm_set_enabled(pio, calibrationSM, false);

    pio_remove_program(pio, &calibration_program, calibrationOffset);
    pio_remove_program(pio, &residue_program, residueOffset);

    multislopeSM = pio_claim_unused_sm(pio, true);
    uint multislopeOffset = pio_add_program(pio, &ms_program);

    residueSM = pio_claim_unused_sm(pio, true);
    residueOffset = pio_add_program(pio, &residue_program);

    ms_program_init(pio, multislopeSM, multislopeOffset, PWMA, COMP, div, MEAS);
    residue_program_init(pio, residueSM, residueOffset, MISO, div);

    pio_sm_set_enabled(pio, multislopeSM, true);
    pio_sm_set_enabled(pio, residueSM, true);

    get_counts(50);

    sleep_ms(1000);

    setMuxState(MUX_GND);
    sleep_us(100);
    get_counts(pwmCycles);
    get_result();

    gndCounts = result;

    sleep_ms(100);

    setMuxState(MUX_RAW);
    sleep_us(100);
    get_counts(pwmCycles);
    get_result();

    rawCounts = result;

    sleep_ms(100);

    setMuxState(MUX_GND);

    while(true)
    {
        newInput = scanf("%s", &inputBuffer, 31);         // Read input from serial port

        // while(!regs.conversionStatus);

        // setMuxState(MUX_GND);

        // sleep_ms(1);
        // get_counts(pwmCycles);
        // get_result();

        // gndCounts = result;

        // setMuxState(MUX_IN);

        sleep_ms(1);
        get_counts(pwmCycles);
        get_result();

        inCounts = result;

        voltage = ((double)(inCounts - gndCounts)/(double)(rawCounts - gndCounts)) * vrefAbs;

        // regs.output = voltage;
        // sleep_ms(1);
        // regs.conversionStatus = 0;

        printf("%e\n", voltage);

        // printf("%d, %d, %d, %g\n", gndCounts, rawCounts, inCounts, voltage);

        // printf("%d, %d, %d\n", N1, N2, N3);

        // sleep_ms(500);

    }
    
    return 0;
}

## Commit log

2022-04-24 Added PCB files
    [Multislope 3I-rounded.kicad_pcb, Multislope 3I.kicad_pcb, Multislope 3I.kicad_sch]
2022-04-25 PCB compact-ified
    [Multislope 3I.kicad_pcb, Multislope 3I.kicad_sch]
2022-04-25 removed redundant files
    [Multislope 3I-rounded.kicad_pcb, Multislope 3I.kicad_pcb, Multislope 3I.kicad_sch]
2022-04-26 pcb completed
    [Multislope 3I.kicad_pcb, Multislope 3I.kicad_sch]
2022-04-26 'final' PCB
    [Multislope 3I-B_Cu.gbr, Multislope 3I-B_Mask.gbr, Multislope 3I-B_Paste.gbr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]
2022-04-26 minor mistakes fixed
    [Multislope 3I-B_Cu.gbr, Multislope 3I-B_Mask.gbr, Multislope 3I-B_Paste.gbr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]
2022-04-28 pcb final touches
    [Multislope 3I.kicad_pcb, Multislope 3I.kicad_sch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]
2022-07-03 added basic pico program
2022-07-11 Schematic updated
    [Multislope 3I.kicad_sch]
2022-07-11 Reference startup circuit added
    [Multislope 3I-B_Cu.gbr, Multislope 3I-B_Mask.gbr, Multislope 3I-B_Paste.gbr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]
2022-07-11 fixed PIO stalling
2022-07-18 Updated Schematic
    [Multislope 3I.kicad_pcb, Multislope 3I.xlsx]
2022-07-18 added code to print temperature
2022-07-20 concept interrupt ADC code
2022-07-28 added experimental DMA ADC reading
2022-07-28 small PIO pin state fix
2022-08-02 fixed DMA not working after first cycle
2022-08-06 Updated Schematic PDF
2022-08-08 added RP2040 ADC output for testing
2022-09-30 PCB Finalized
    [Multislope 3I.kicad_pcb]
2023-01-06 updated files
    [Multislope 3I.kicad_pcb]
2023-01-11 Create Multislope Run 3.xlsx
    [Multislope Run 3.xlsx]
2023-06-03 ms.pio
    - One small aesthetic change
    - Added MCP3202 SPI code with instructions, to do
2023-06-22 Optimized PIO Code 1
    [Multislope 3I.kicad_sch]
2024-07-01 Major code update 01.07.2024
    Restarted work on finishing this project after more than a year.
    Code was completely refactored. DMA/PIO interrupt was removed, and two state machines from the same PIO block were loaded with runup and (mock) residue code and sychronized using interrupt 0 (irq 0).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
    [Multislope 3I.kicad_sch]
2024-07-22 fixed residue ADC bug
    readings delayed by one cycle, fixed by clearing fifos before measurement
2024-07-24 on-board V calculation
2024-07-25 refactored code to fit with current SDK version
2024-07-26 fixed runup calculation issue
    Jaromir runup injects ±14 units worth of charge, not ±15
    [main.cpp]
2024-08-13 Updated project.log with new theory about 100 NPLC INL error with Runup 2
    [main.cpp]
2024-08-19 moved to pico vscode extension (slightly buggy)
    [main.cpp]
2024-08-28 updated project.log with TMT multislope noise results
    [SW_RP2350.cpp, main.cpp]
2024-08-29 updated project.log with crystal and GPIO bug information
    [SW_RP2350.cpp]
2024-10-11 updated project log, fixed RP2040 software
    [SW_RP2350.cpp, main.cpp]
